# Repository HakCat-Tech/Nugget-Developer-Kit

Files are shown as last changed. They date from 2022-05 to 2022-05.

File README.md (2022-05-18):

# WiFi Nugget Developer Kit v2.2
This repository contains KiCAD design files for the WiFi Nugget Developer Kit PCB.  The current version of this release is `2.2`.
This kit is designed to teach beginners basic hardware assembly skills, and features both through-hole and surface mount components.
<p align="center">
  <br>
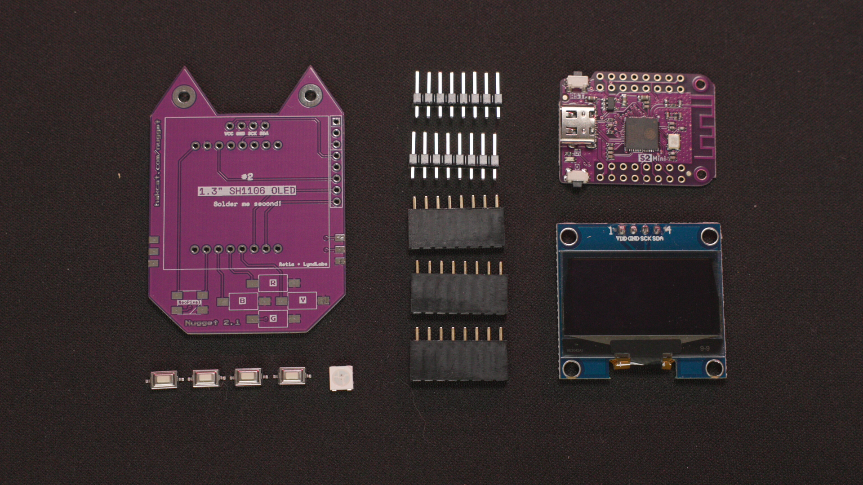
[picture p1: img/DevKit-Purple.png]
  
  <br>
  <b>ESP32-S2 DevKit Components</b>
  <br>
  <br>
</p>

## Features
This kit is designed to work with the [Wemos "mini" form factor](https://www.wemos.cc/en/latest/), and accomodates breakouts for the ESP8266, ESP32-S2, and some other Espressif based board designs.
The developer kit includes:

- **Buttons** (D-Pad style, 4 Buttons)
- **RGB LED** (WS2812B NeoPixel)
- **WiFi Microcontroller** ([D1](https://www.wemos.cc/en/latest/d1/index.html)/[S2](https://www.wemos.cc/en/latest/s2/index.html)/[C3](https://www.wemos.cc/en/latest/c3/index.html) Mini)
- **Screen** (SH1106 1.3" OLED)
- **Expansion Headers** 
- **Screw Assembly*** (M2.5 Screws / Threaded Inserts)
- **3D Printed Case***

\* *We ditched the screw assembly on newer Nuggets, which use a snap-fit case.  You can find links to our case designs below.*

## Resources
- [Assembly Guide]()
- [3D printed cases](https://github.com/HakCat-Tech/WiFi-Nugget-Cases)

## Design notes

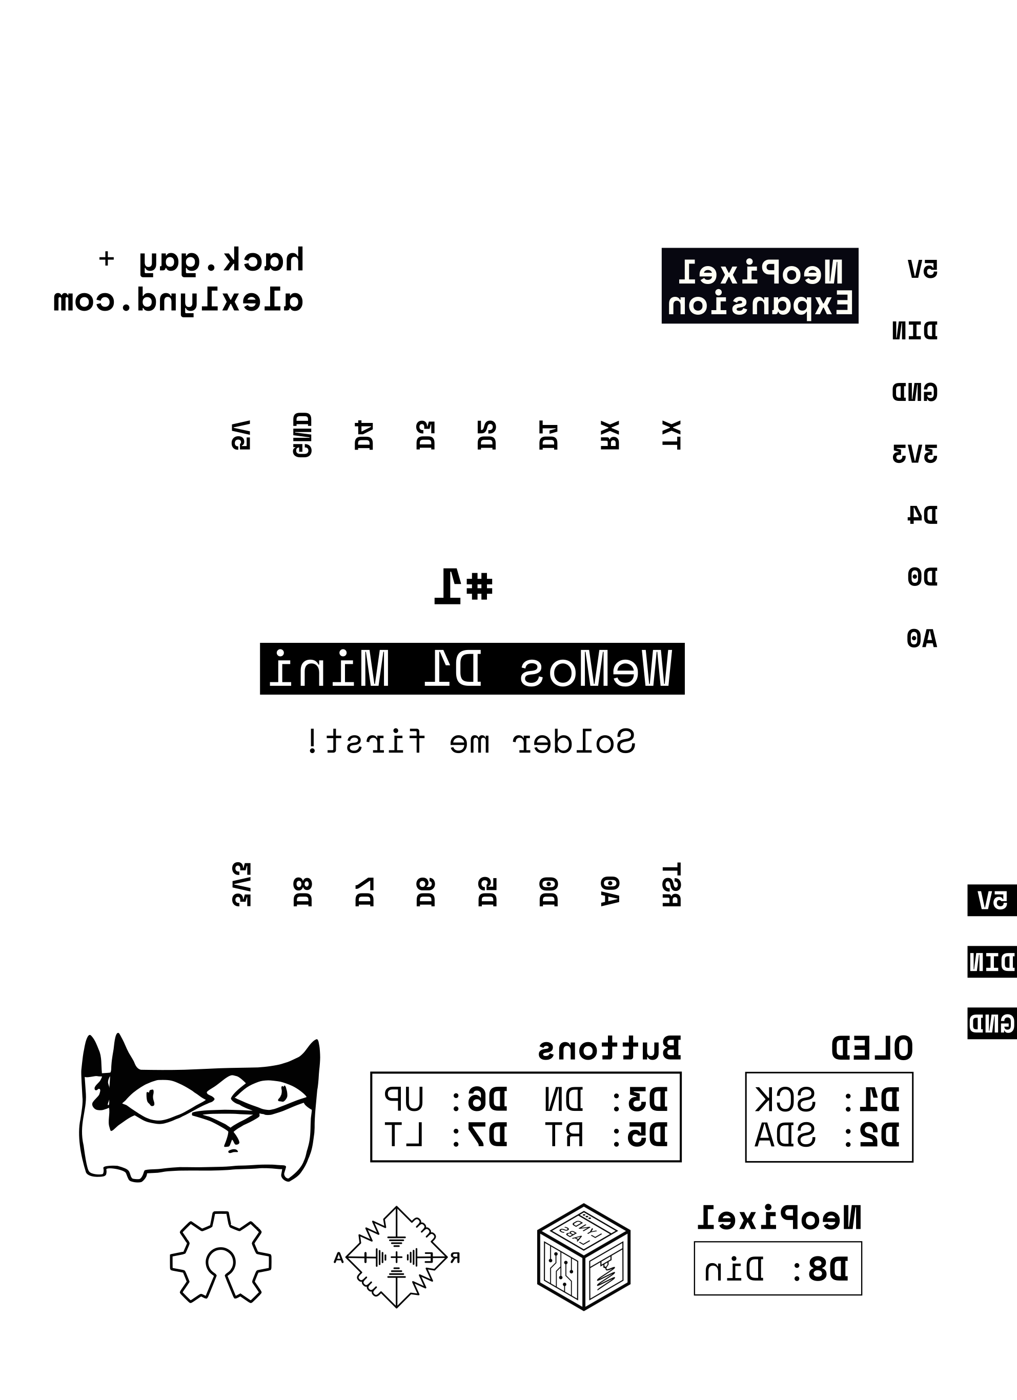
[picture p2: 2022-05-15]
v2.2-Dev-Kit/assets/.svg2shenzhen-cache/images/B.SilkS_g836.png

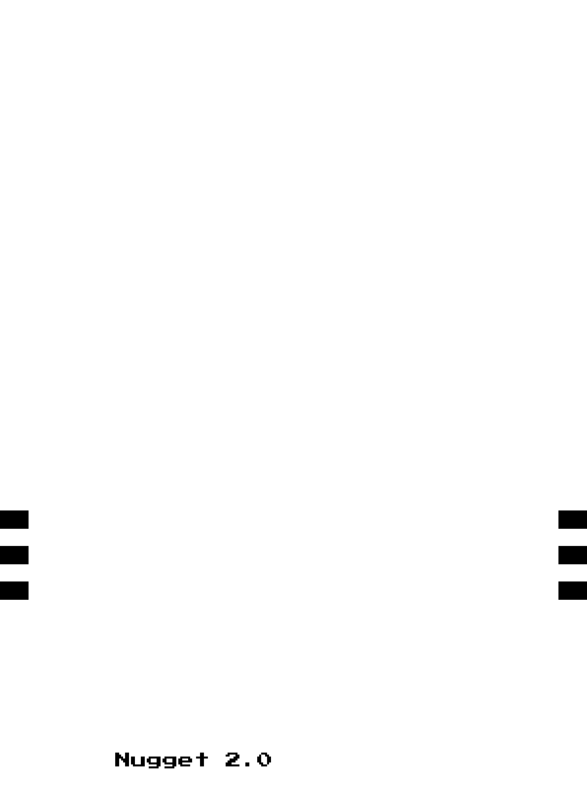
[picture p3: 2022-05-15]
v2.2-Dev-Kit/assets/footprint/.svg2shenzhen-cache/images/F.Mask_g842.png

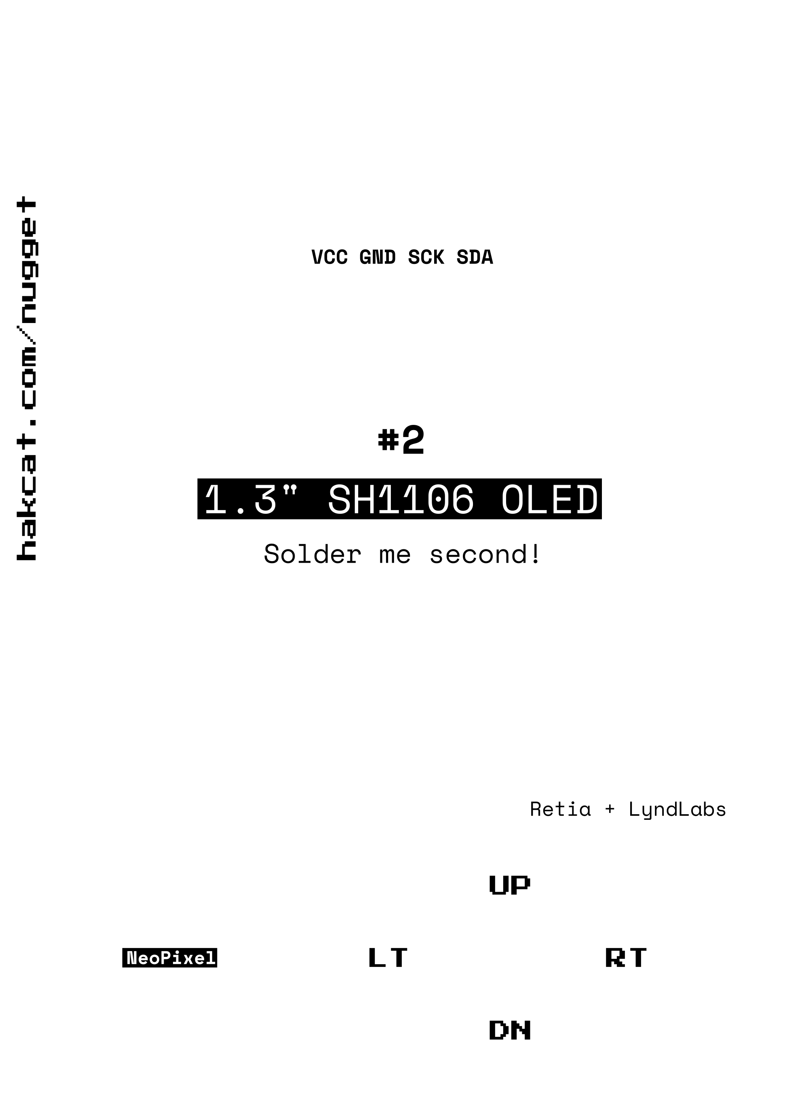
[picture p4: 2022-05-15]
v2.2-Dev-Kit/assets/.svg2shenzhen-cache/images/F.SilkS_g838.png

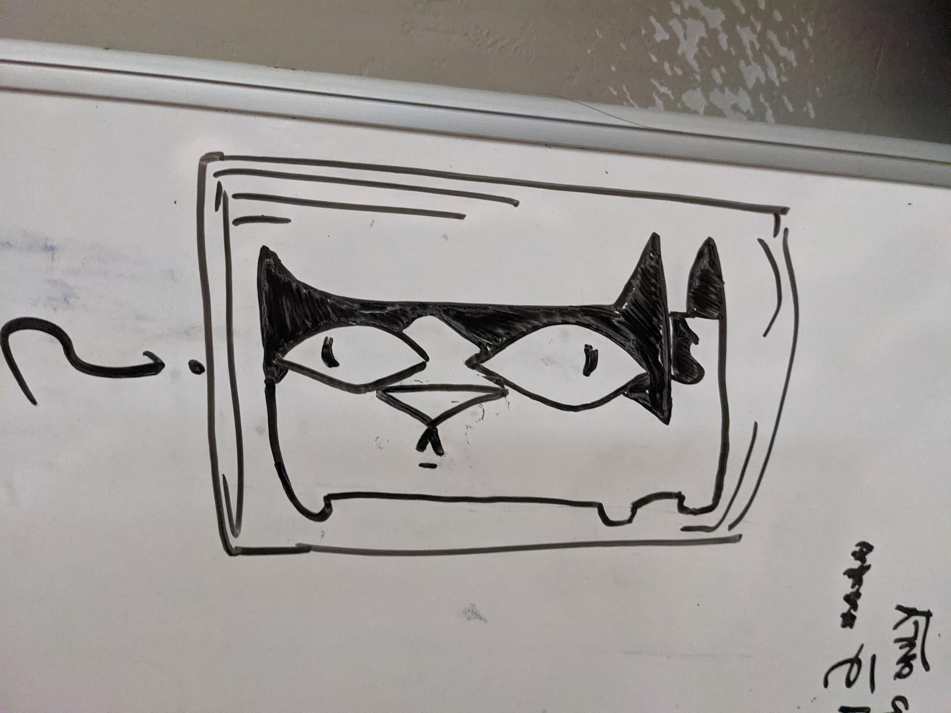
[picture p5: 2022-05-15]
v2.2-Dev-Kit/assets/art/wide-nugg.jpeg

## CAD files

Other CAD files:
v2.2-Dev-Kit/assets/outline/DevKit-Outline.FCStd
v2.2-Dev-Kit/assets/outline/DevKit-Outline.dxf

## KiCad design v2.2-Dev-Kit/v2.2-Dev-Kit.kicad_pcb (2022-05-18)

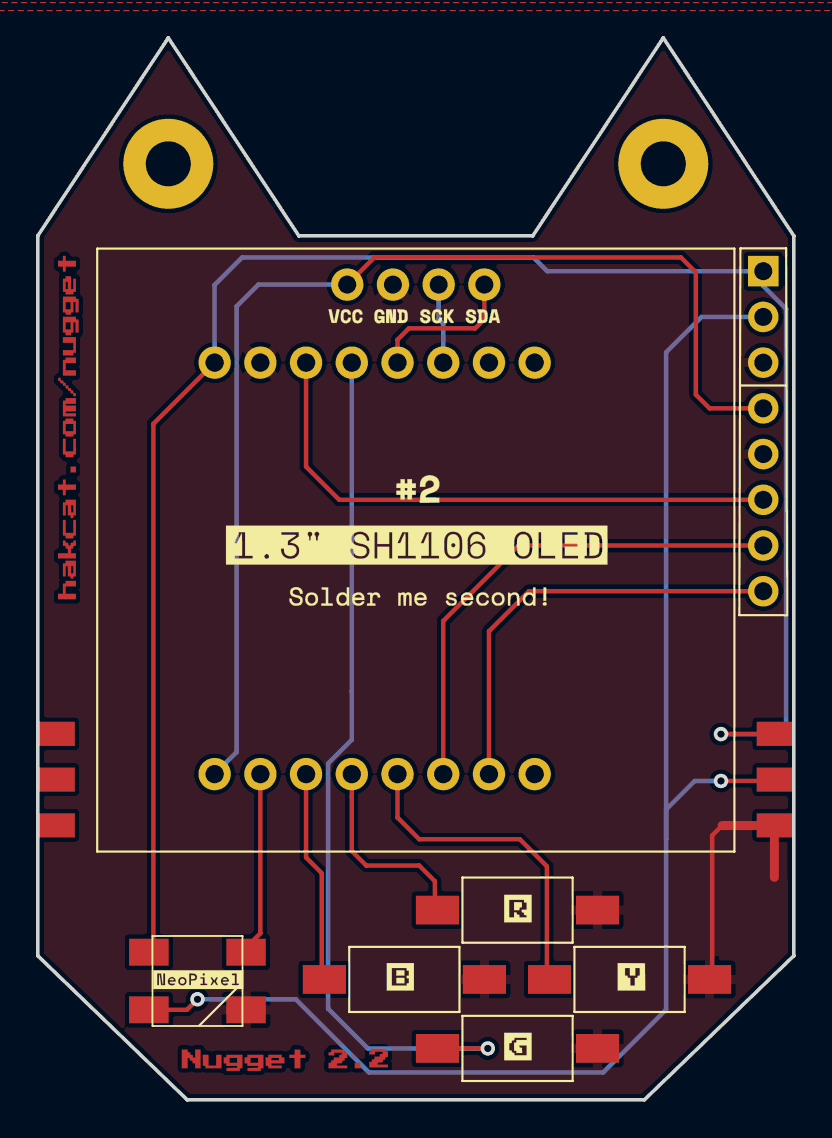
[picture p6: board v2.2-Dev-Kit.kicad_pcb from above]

Board: 2 copper layers, 42.0 x 59.0 mm, 9 parts (1 on the bottom side), 14 nets.

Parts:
D1: WS2812B; LED_WS2812B_PLCC4_5.0x5.0mm_P3.2mm_idiot_proof
J1: 8 Pin Header; PinHeader_1x08_P2.54mm_Vertical
Ref**: Val**; Nugget-PCB-Art
SW1: Up; SW_SPST_FSMSM
SW2: Down; SW_SPST_FSMSM
SW3: Left; SW_SPST_FSMSM
SW4: Right; SW_SPST_FSMSM
U1: WeMos D1 Mini; wemos-d1-mini-with-pin-header-and-connector
U2: SH1106 OLED; SH1106-128x64-OLED

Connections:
+5V: D1.1, J1.1, U1.9
/D5: SW4.1, U1.4
/D6: SW1.1, U1.5
/D7: SW3.1, U1.6
GND: D1.3, J1.3, J1.5, SW1.2, SW2.2, SW3.2, SW4.2, U1.10, U2.2
unnamed: J1.4, U1.8, U2.1
unnamed: U1.14, U2.3
unnamed: U1.13, U2.4
unnamed: D1.2, J1.2
unnamed: D1.4, U1.7
unnamed: J1.8, U1.2
unnamed: J1.7, U1.3
unnamed: J1.6, U1.11
unnamed: SW2.1, U1.12

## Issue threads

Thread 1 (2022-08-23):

Automatic DRC build check & Gerber file export

AlexLynd, 2022-08-23:
Requesting a CI build script to automatically run a design rule check after pushing to the dev branch, and auto generate the Gerber files for fabrication.

AlexLynd, 2022-08-23:
We've been set back a month on the current prototype cause of stupid issues like forgetting to pour the ground plane, which this would help with.

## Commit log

2022-05-15 publish v2.0 PCB design files & art assets
    [DevKit-Outline.FCStd, DevKit-Outline.dxf, v2.0-Dev-Kit.kicad_pcb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]
2022-05-15 upload v2.1 files
    [DevKit-Outline.FCStd, DevKit-Outline.dxf, v2.0-Dev-Kit.kicad_pcb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]
2022-05-18 update v2.2 - delete old graphics
    [DevKit-Outline.FCStd, DevKit-Outline.dxf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]
2022-05-19 add export files
    [v2.2-Dev-Kit-B_Cu.gbl, v2.2-Dev-Kit-B_Mask.gbs, v2.2-Dev-Kit-B_Paste.gbp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]
